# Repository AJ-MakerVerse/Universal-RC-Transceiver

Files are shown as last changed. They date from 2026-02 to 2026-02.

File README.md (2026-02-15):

**Universal RC Transceiver**

This project is a high-performance, DIY Radio Control Transmitter designed to be a "Master Remote" for future robotics projects. While the transmitter is a complete hardware build (Universal PCB + 3D Printed Case), the receiver is provided as a reference prototype to jumpstart integration into any Arduino-based vehicle.

**The Vision**  
The goal was to create a single, reliable handheld controller with a standardized data packet. Whether you are building a drone, a rover, or a robotic arm, you simply drop the provided Receiver code into your project and start mapping controls.

**Features**  
Hardware Capabilities:

* Multi-Input Control: Supports 2 Joysticks (4-axis), 2 Potentiometers, 4 DPDT Switches, and 2 Push Buttons.
* Motion Control: Integrated MPU-6500 IMU allows for tilt-based steering (Pitch/Roll) with a dedicated "Tare" deadman switch.
* Universal Build: Designed for a standard Universal PCB (Perfboard), making it accessible for DIY builders.
* Ergonomic Design: Custom 3D-printable housing for a professional handheld feel.

Firmware Intelligence:

* High-Speed Link: Operates at 100Hz (10ms refresh rate) for low-latency control.
* Optimized Payload: Uses a Packed C++ Struct (17 bytes) to fit all data into a single nRF24L01 packet (under the 32-byte limit).
* Bit-Packing: Compresses 8 digital inputs into a single byte to save bandwidth and improve reliability.
* Error Handling: Built-in LED blink codes for hardware troubleshooting (Radio or IMU disconnected).
* Robust Protocol: Uses 16-bit CRC error detection, Auto-Acknowledgment, and a specific 250kbps data rate for maximum range and penetration.

**Project Structure**  
This repository is organized into two main modules:

**1. Transmitter (TX)**  
The control hub of the system.

* Firmware: Source code and library dependencies.
* Hardware: Universal PCB layout and wiring diagrams.
* STLs: 3D Printable files for the transmitter case.

**2. Receiver (RX)**  
The vehicle/device-side module.

* Firmware: Reference code to parse data and print to Serial Monitor.
* Hardware: Breadboard wiring guide for prototyping.

Each sub-folder contains its own dedicated README with specific assembly and setup instructions.

**Quick Start**  

* Build the Hardware: Start with the Transmitter Hardware Guide.
* Library: Install RF24 and FastIMU libraries in your Arduino IDE.
* Flash the Code: Upload the TX Firmware and RX Firmware.
* Test: Power on both units and verify the link.

**License**  
This project is licensed under the MIT License.

**Contributing**  
Feel free to fork this project, report bugs via Issues, or submit Pull Requests to improve the protocol or hardware designs!

**To see more of my projects, feel free to connect with me on LinkedIn - https://www.linkedin.com/in/abhayjain-makerverse**

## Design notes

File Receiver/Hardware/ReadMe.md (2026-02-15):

**Receiver Hardware**

This folder contains the wiring instructions for the receiver prototype. Currently, the receiver is designed for a breadboard setup to allow for quick testing and easy integration into different projects.

**Documentation Files**	

* Breadboard Diagram: Visual guide for jumper wire placement.
* Bill of Materials (BoM): A full list of components required for the build.

**Pin Mapping (Arduino Nano)**  
Since the receiver only requires the nRF24L01 module, the wiring is straightforward:

* VCC  = 3.3V
* GND  = GND	
* CE   = D9	 
* CSN  = D10	 
* SCK  = D13	
* MOSI = D11	
* MISO = D12

**Pro Tip:** Breadboards are notorious for "noisy" power lines. If the receiver is struggling to stay connected, plug a 10µF-100µF capacitor directly into the breadboard across the nRF24L01's VCC and GND pins.

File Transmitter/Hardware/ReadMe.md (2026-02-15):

**Transmitter Hardware**  

This folder contains the physical assembly details for the Universal RC Transmitter. The build is designed to be soldered onto a standard Universal PCB for a compact and durable finish.

**Documentation Files**
* Wiring Diagram: The complete schematic and point-to-point wiring guide.  
* Bill of Materials (BoM): A full list of components required for the build.

**Pin Mapping Table**  
Use the follwoing list to wire your components to the Arduino Nano:  

**Digital Inputs (Switches & Buttons)**

* DPDT_1 =  D6	
* DPDT_2 =	D7	
* DPDT_3 =	D0 (RX)	
* DPDT_4 =	D1 (TX)	
* PB_1   =	D5	
* PB_2   =	D2	
* Tare   =  D8

**Analog Inputs (Joysticks \& Pots)**

* JS_1_VRy = A0	
* JS_1_VRx = A1	
* JS_1_SW  = D4	
* JS_2_VRy =	A6	
* JS_2_VRx =	A7	
* JS_2_SW  =	D3	
* Pot_1    =	A2	
* Pot_2		 =  A3

**Communication Modules**  
* nRF24L01 Radio 	\[I2C] -	D9 (CE), D10 (CSN), D11 (MOSI), D12(MISO), D13(SCK)
* MPU-6500 IMU	\[SPI] -	A4 (SDA), A5 (SCL)

**Assembly Notes**

Universal PCB Layout:

* Placement: Place the Arduino Nano in the center using female header pins. This allows you to replace the Nano if it ever burns out.
* Power: The nRF24L01 is very sensitive to power noise. It is highly recommended to solder a 10µF to 100µF capacitor across the VCC and GND pins of the radio module.
* Pull-ups: The firmware uses internal INPUT\_PULLUP. Ensure all switches and buttons are wired to GND when closed.

IMU Orientation:  
Mount the MPU-6500 flat on the PCB. If your "Forward" tilt is giving you "Roll" data instead of "Pitch," check the orientation of the module or adjust the axes in the firmware.

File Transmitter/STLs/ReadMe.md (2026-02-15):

**Transmitter STLs**

This folder contains the 3D-printable files for the transmitter enclosure. The design focuses on ergonomics, ensuring a comfortable grip for long sessions, and easy access to all switches and joysticks.

**STL Files**

* Enclosure - Top: The main faceplate with cutouts for joysticks, buttons, and switches.
* Enclosure - Bottom: The rear shell, designed to house the Universal PCB.
* Potentiometer - Knob: Custom-fit knobs for the two potentiometers (print 2x).
* Button - Cap: Protective caps for the tactile push buttons to improve surface area and feel (pint 3x). 

**Recommended Print Settings**  
For the best fit and durability, use the following settings:

* Material	-	PLA (for ease) or PETG (for durability)
* Layer Height	-	0.2mm
* Infill	-	10% (Lightning)
* Supports	-	None

**Post-Processing**  
If you notice stringing, abrasions, or if the parts aren't meshing perfectly, do some light sanding on the contact edges.

**Assembly**

* PCB Placement: 	Place the assembled Universal PCB/Transmitter unit into the Enclosure - Bottom. Ensure it is seated properly.
* Button Preparation: 	Place the 3 Button Caps into their respective slots in the Enclosure - Top.
* The Snap: 		Align the Enclosure - Top with the Enclosure - Bottom. Press firmly until you hear the parts snap together.
* Potentiometers: 	Screw on the metal nut that came with your potentiometer to secure the electronics to the shell.
* Knobs: 		Press the Potentiometer - Knob over the potentiometer shafts.
* Arduino: 		Finally, insert your Arduino Nano into the female header pins on your board.

**Troubleshooting**

* Tight Fit: If the cap stick, sand the sides down slightly, and ensure they move freely
* Alignment: Ensure that the components are aligned with enclosure's slots.

**You can also find the files on Printables:** https://www.printables.com/model/1602552-universal-rc-transceiver

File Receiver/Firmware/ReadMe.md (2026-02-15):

**Receiver Firmware**

This folder contains the reference code for the Arduino Nano receiver. Its primary purpose is to intercept the data packets from the Universal Transmitter and output the values to the Serial Monitor for debugging and calibration.

**Required Libraries**  
To compile this code, you must install the following library:

* RF24 (by TMRh20): For nRF24L01 radio communication.

**Logic Overview**  
The receiver acts as a passive listener. It is configured to match the Transmitter's settings exactly:

* Address: "00009"
* Channel: 105
* Data Rate: 250 kbps
* CRC: 16-bit

**The "Packed" Struct**  
The most critical part of this firmware is the Values struct. Because the Transmitter uses \_\_attribute\_\_((packed)), the Receiver must use the exact same definition to ensure the bytes align correctly in the Arduino's memory.

**Using the Serial Monitor**  
Once the code is flashed, open the Serial Monitor in the Arduino IDE to see the live data stream.

Settings:

* Baud Rate: 115200
* Format: The output will display PB (Push Buttons), DPDT (Switches), POT (Potentiometers), JS (Joysticks), and IMU (Pitch/Roll) values.

Reading the Output

* Digital Pins: Values are shown as 0 (Released) or 1 (Pressed).
* Analog Pins: Values range from 0 to 1023.
* IMU: Pitch and Roll are displayed in degrees. Note that the code divides the incoming value by 10 (e.g., a transmitted 450 becomes 45.0°).

**Troubleshooting the Link**  
If you don't see data in the Serial Monitor:

* Radio Check: On startup, the code checks if the nRF24L01 is connected. If you see "Radio Hardware Not Found!", check your SPI wiring.
* Address Mismatch: Ensure the Address variable in both TX and RX code is exactly "00009".
* Power Issues: The nRF24L01 on a breadboard is prone to electrical noise. If the data is "choppy" or stops randomly, add a capacitor (10µF+) across the radio's VCC and GND.

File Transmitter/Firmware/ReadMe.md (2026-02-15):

**Transmitter Firmware**

This folder contains the source code for the Universal RC Transmitter. The firmware is optimized for high-speed transmission (100Hz) and features advanced IMU data processing for motion control.

**Required Libraries**  
To compile this code, you must install the following libraries in the Arduino IDE:

* RF24 (by TMRh20): For nRF24L01 radio communication.
* FastIMU (by Tutto): For high-speed MPU-6500 data processing.
* SPI \& Wire: (Built-in Arduino libraries).

**Radio Configuration**  
The transmitter is configured for maximum reliability and low latency:

* Channel: 105 (2.505 GHz)
* Data Rate: 250 kbps (Chosen for better range and signal penetration).
* Payload: Dynamic payloads enabled with 16-bit CRC error detection.
* Power Level: Currently set to RF24\_PA\_MIN for bench testing.

Note: For field use, uncomment radio.setPALevel(RF24\_PA\_MAX); in the setup() function.

**Motion Control (IMU)**  
The firmware uses an MPU-6500 to calculate Pitch and Roll.

* Tare System: Pin D8 acts as a "Deadman Switch."
* The IMU only streams data when D8 is held down.
* On press, it "Tares" (zeros) the current orientation, allowing you to use the remote in any comfortable position.
* Complementary Filter: We use a filter coefficient of 0.96 to combine Accelerometer and Gyroscope data, providing smooth angles without "drift."

**Data Efficiency (Bit-Packing)**  
To keep the latency low, we pack all inputs into a custom C++ struct. This allows us to send 14 different inputs in a single 17-byte packet.

**Troubleshooting (Blink Codes)**  
If the transmitter fails to start, the Built-in LED (Pin 13) will blink a specific pattern:

* Single Blink: nRF24L01 Radio Hardware not found. Check SPI wiring and power.
* Double Blink: MPU-6500 IMU not found. Check I2C (A4/A5) connections.

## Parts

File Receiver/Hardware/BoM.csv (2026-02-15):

Item | Qty
Arduino UNO | x1
nRF24L01 | x1

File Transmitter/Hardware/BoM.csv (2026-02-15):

Item | Qty | Specs
Arduino Nano R3 | x1 | -
nRF24L01 | x1 | -
MPU - 6500 | x1 | -
Momentary Push Button | x3 | 12 x 12 x 7 mm
Potentiometer | x2 | B10K
HW - 504 Joystick | x2 | -
DPDT Slide Switch | x2 | 6 Pin
DC Barrel Power Jack | x1 | -
SPDT Slide Switch | x1 | -
Battery | x1 | 7V - 12V
Male & Female Header Pins | as req. | -
Jumper Wires | as req. | -
Universal PCB | x1 | S895

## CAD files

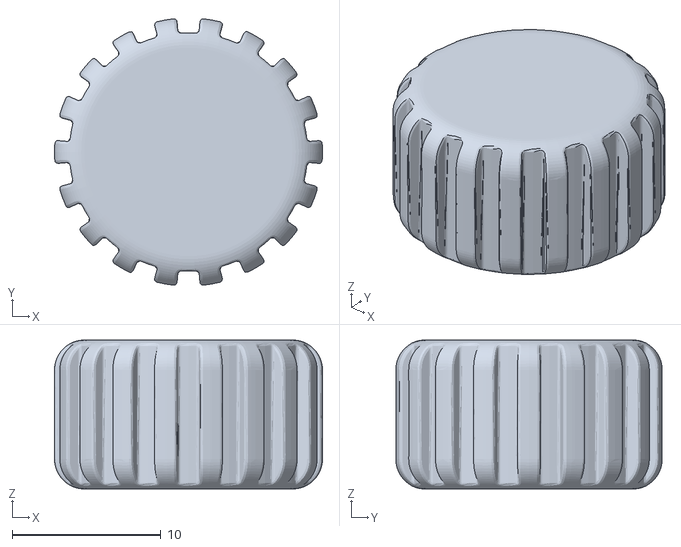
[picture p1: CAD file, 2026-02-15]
Transmitter/STLs/Potentiometer - Knob.stl
18.0 x 17.9 x 10.0

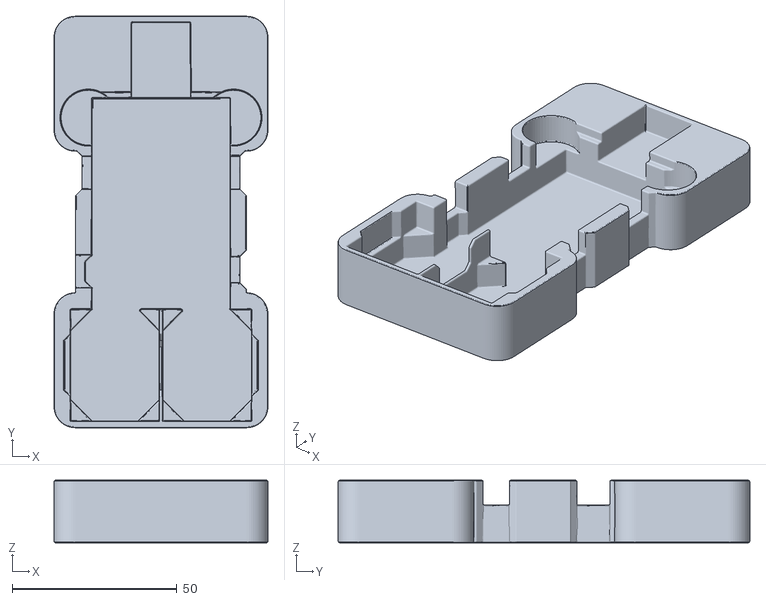
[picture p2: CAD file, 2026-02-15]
Transmitter/STLs/Enclosure - Bottom.stl
65.0 x 125.0 x 19.0

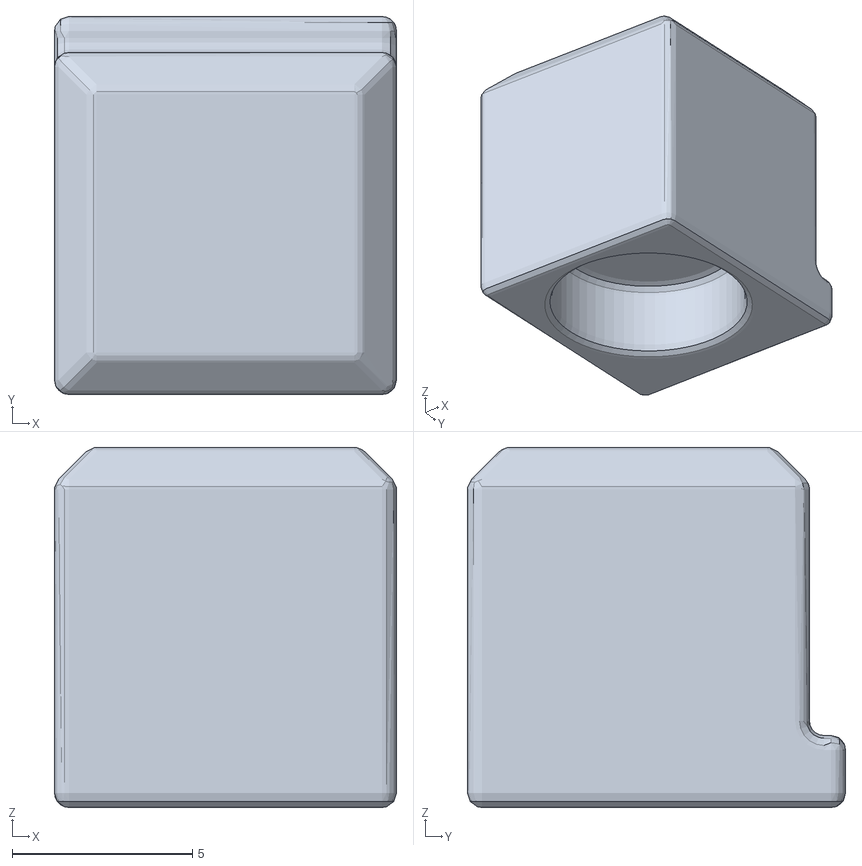
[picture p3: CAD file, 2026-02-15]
Transmitter/STLs/Button - Cap.stl
9.50 x 10.5 x 10.0

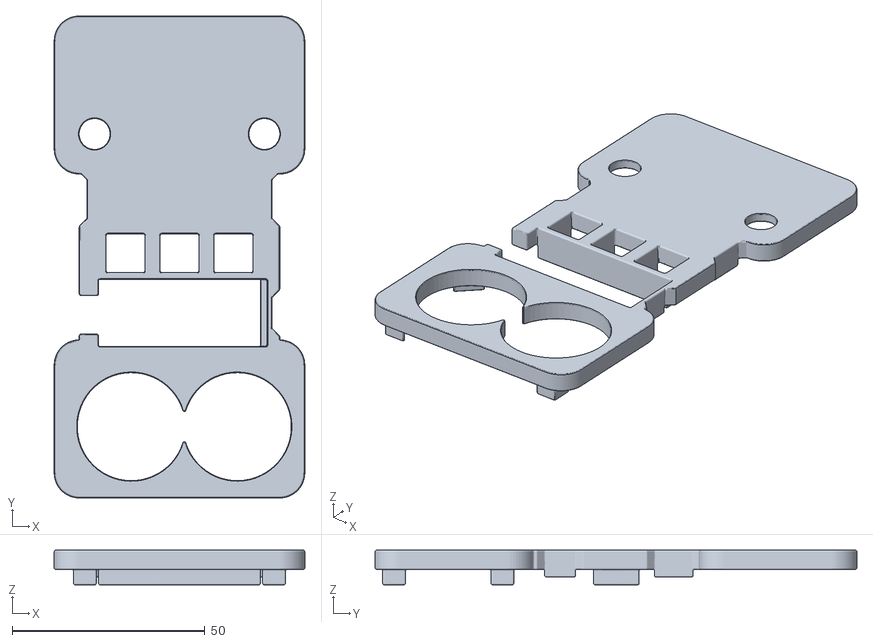
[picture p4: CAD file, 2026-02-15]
Transmitter/STLs/Enclosure - Top.stl
65.0 x 125.0 x 9.00

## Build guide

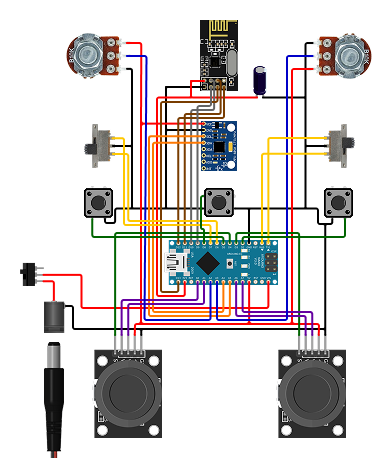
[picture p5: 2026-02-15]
Transmitter/Hardware/RC _ Transmitter Wiring Diagram.png

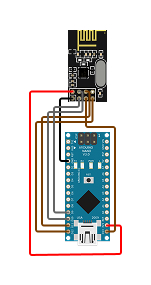
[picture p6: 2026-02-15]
Receiver/Hardware/RC_Receiver Wiring Diagram.jpg

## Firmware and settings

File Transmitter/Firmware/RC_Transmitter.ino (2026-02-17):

/*
Arduino Nano Pinout
  Digital Input:    |   Analog Input:    |    SPI Communication Pins:   |   I2C Communication Pins:

  RX0 = DPDT_4      |   A0 = JS_1_VRy    |    D9  = CE                  |   A4 = SDA
  TX1 = DPDT_3      |   A1 = JS_1_VRx    |    D10 = CSN                 |   A5 = SCL
  D2  = PB_2        |   A2 = POT_1       |    D11 = MOSI                |
  D3  = JS_2_SW     |   A3 = POT_2       |    D12 = MISO                |
  D4  = JS_1_SW     |   A6 = JS_2_VRy    |    D13 = SCK                 |
  D5  = PB_1        |   A7 = JS_2_VRx    |                              |
  D6  = DPDT_1      |                    |                              |
  D7  = DPDT_2      |                    |                              |
  D8  = Tare/PB_3   |                    |                              |
*/

//SPI Communication Library
#include <SPI.h>                                      //D11 = MOSI ; D12 = MISO ; D13 = SCK

//nRF24L01 Library
#include <nRF24L01.h>
#include <RF24.h>

//I2C Communication Library
#include <Wire.h>                                     //A4 = SDA ; A5 = SCL

//MPU-6500 Library
#include <FastIMU.h>

//CE, CSN Pins
RF24 radio(9, 10); 

//Transmitter Address
const byte Address[6] = "00009";                      //Must be same as Receiver Address

//MPU-6500 I2C Address
const uint8_t IMU_ADDRESS = 0x68;                     //IMU: Inertial Measurement Unit Sensor
const uint8_t Tare = 8;                               //IMU Deadman Switch

//MPU-6500 Object
MPU6500 IMU;

//IMU Data Structure
calData Calib;                                        //Calibration Data
AccelData Accel;                                      //Accelerometer Data
GyroData Gyro;                                        //Gyroscope Data

//Pitch and Roll Calculation Variables
float OAx, OAy, OAz, OGx, OGy;                        //Accel & Gyro Offset values 
float roll, pitch, sRoll, sPitch;                     //s : snapshot values
float alpha = 0.96;                                   //Complementary Filter
unsigned long time;
bool running = false;                                 //IMU Tracking Status

//Transmitter Data Type
struct __attribute__((packed)) Values{
  uint8_t Digital;                                    //8 digital inputs packed into 8 bits (Bit-Packing)     :1 Bytes
  uint16_t Analog[6];                                 //6 analog inputs (0 - 1023)                            :12 Bytes
  int16_t Euler[2];                                   //Euler Angles (Pitch and roll)                         :4 Bytes
};                                                    //Total                                                 :17 Bytes < 32 Bytes

//Transmitter Object
Values Data;

//Analog Input Pin Array
uint8_t analogPins[] = {A0, A1, A2, A3, A6, A7};

//Accel & Gyro Value Calibration Function
void calibrate(bool GyroOnly){
  float Ax=0, Ay=0, Az=0, Gx=0, Gy=0;
  for(int i=0; i<100; i++){
    IMU.update();                                     //Update IMU readings
    IMU.getAccel(&Accel); IMU.getGyro(&Gyro);         //Getting current IMU Data
    //Sum of 100 Values
    Ax+=Accel.accelX; Ay+=Accel.accelY; Az+=Accel.accelZ;     
    Gx+=Gyro.gyroX; Gy+=Gyro.gyroY;
    delay(5);
  }
  if(!GyroOnly){ 
    OAx=Ax/100; OAy=Ay/100; OAz=(Az/100)-1.0;         //Calculating Accel Offset Values as avg of 100 values
  }
  OGx=Gx/100; OGy=Gy/100;                             //Calculating Gyro Offset Values as avg of 100 values
}

//Euler Angles Calculation Function
void Angles(bool Track){
  IMU.update();                                       //Update IMU readings
  IMU.getAccel(&Accel); IMU.getGyro(&Gyro);           //Getting current IMU Data

  //Subtract the offset values from current values to get the data close to 0
  float Ax = Accel.accelX-OAx, Ay = Accel.accelY-OAy, Az = Accel.accelZ-OAz;    
  float Gx = Gyro.gyroX-OGx, Gy = Gyro.gyroY-OGy;

  float dt = (millis()-time)/1000.0; time = millis(); //Calculating Instantaneous time
  
  //Calculating Roll and Pitch based on Accel Values
  float rollAccel = atan2(Ay, Az) * 180.0/PI;
  float pitchAccel = atan2(-Ax, sqrt(Ay*Ay + Az*Az)) * 180.0/PI;

  if (Track){                                         //Jump directly to physical angle on first frame
    roll = rollAccel;
    pitch = pitchAccel;
  }
  else{                                               //Use normal filter during streaming
    roll = alpha * (roll + Gx * dt) + (1.0-alpha) * rollAccel;
    pitch = alpha * (pitch + Gy * dt) + (1.0-alpha) * pitchAccel;
  }
}

void setup(){
  //put your code here, to run once:

  Wire.begin();                                       //Initialize I2C Communication
  Wire.setClock(400000);                              //Set I2C to 400kHz for faster IMU updates

  //Initializing nRF24L01 Module
  if (!radio.begin()){                                //Initializes Radio Chip
    pinMode(13, OUTPUT);                              //Explicitly take control for error signal
    while (1){
      digitalWrite(13, HIGH); delay(1000);
      digitalWrite(13, LOW);  delay(2000);
      //Built-In LED - Single Blink : Radio is disconnected
    } 
  }                                                   //If radio fails, stop here (Safety Check)                                 

  radio.enableDynamicPayloads();                      //Allow Packets of different Byte sizes
  radio.setAutoAck(true);                             //Enables Auto-Acknowledgment
  radio.setCRCLength(RF24_CRC_16);                    //Uses a 16-bit checksum for better error detection

  radio.setChannel(105);                              //Channel 0-125 :: 2.4 - 2.525 GHz
  radio.setDataRate(RF24_250KBPS);                    //Sets Transmission Speed to 250 kbps (250 kbps - 2 Mbps)

  radio.setPALevel(RF24_PA_MIN);                      //Sets Power Amplifier (PA) to MINIMUM, Range: 1 - 2 Meters
  //radio.setPALevel(RF24_PA_LOW);                      //Range: 5 - 15 Meters
  //radio.setPALevel(RF24_PA_HIGH);                     //Range: 15 - 30 Meters
  //radio.setPALevel(RF24_PA_MAX);                      //Range: 30 - 70+ Meters

  radio.setRetries(5, 15);                            //1250us delay, 15 retries

  radio.openWritingPipe(Address);                     //Sets the destination address for transmission
  radio.stopListening();                              //Puts radio into Transmitter (TX) Mode

  //Initializing MPU-6500
  if(IMU.init(Calib, IMU_ADDRESS) !=0){               //Initializes IMU Chip
    pinMode(13, OUTPUT);                              //Explicitly take control for error signal
    while (1){
      digitalWrite(13, HIGH); delay(1000);
      digitalWrite(13, LOW);  delay(500);
      digitalWrite(13, HIGH); delay(1000);
      digitalWrite(13, LOW); delay(2000);
      //Built-In LED - Double Blink : IMU is disconnected
    }
  }                                                   //If IMU fails, stop here (Safety Check)

  //Setting Arduino digital pins as INPUT
  for(int i = 0; i <= 8; i++){
    pinMode(i, INPUT_PULLUP);
  }

  calibrate(0);                                       //Calibrating both Accel & Gyro

}

void loop(){
  //put your code here, to run repeatedly:

  static unsigned long lastSend = 0;
  if (millis() - lastSend < 10) return; 
  lastSend = millis();                                //Send data every 10ms (100Hz)

  //Store Roll and Pitch
  bool pressed = (digitalRead(Tare) == LOW);

  if (!running && pressed){                           //IMU is not tracking but the Button is pressed
    calibrate(1);                                     //Calibrating only Gyro to remove Gyro drift
    time = millis();                                  //Reset timer
    Angles(true);                                     //Force filter to match current tilt exactly
    sRoll = roll; sPitch = pitch;                     // Snapshot this as "Zero"
    running = true;                    
  } 
  else if (running){                                  //IMU is tracking
    if (!pressed){                                    //Button is released
      running = false; 
      Data.Euler[0] = 0;  Data.Euler[1] = 0;
    }else{
      Angles(false);                                  //Run normal filter
      Data.Euler[0] = (int16_t)((roll - sRoll) * 10);
      Data.Euler[1] = (int16_t)((pitch - sPitch) * 10);
    }
  }
  else{
    Data.Euler[0] = 0;  Data.Euler[1] = 0;
  }

  //Store Analog Input
  for (int i = 0; i < 6; i++){
    Data.Analog[i] = analogRead(analogPins[i]);
  }

  //Store Digital Input
  Data.Digital = 0;                                   //Clears the Bucket : 0000 0000
  //Data.Digital = ~(PIND);
  for (int i = 0; i <= 7; i++){
    if (digitalRead(i) == LOW){                       //Button pressed
      Data.Digital |= (1 << i);                       //Stores value at the 'i' bit
    }
  }

  radio.write(&Data, sizeof(Data));                   //Transmits the Data
  
}

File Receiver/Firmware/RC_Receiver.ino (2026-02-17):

//SPI Communication Library
#include <SPI.h>                                      //D11 = MOSI ; D12 = MISO ; D13 = SCK

//nRF24L01 Library
#include <nRF24L01.h>
#include <RF24.h>

//CE, CSN Pins
RF24 radio(9, 10); 

//Transmitter Address
const byte Address[6] = "00009";                      //Must be same as Transmitter Address

//Receiver Data Type: Must be same as Transmitter
struct __attribute__((packed)) Values{
  uint8_t Digital;
  uint16_t Analog[6];
  int16_t Euler[2];
}; 

//Receiver Object
Values Data;

void setup() {
  // put your setup code here, to run once:

  Serial.begin(115200);                               //Initialize Serial Monitor

  if (!radio.begin()) {
    Serial.println("Radio Hardware Not Found!");
    while (1);
  }                                                   //Safety Check

  radio.enableDynamicPayloads();                      //Allow Packets of different Byte sizes
  radio.setAutoAck(true);                             //Enables Auto-Acknowledgment
  radio.setCRCLength(RF24_CRC_16);                    //Uses a 16-bit checksum for better error detection

  radio.setChannel(105);                              //Channel 0-125 :: 2.4 - 2.525 GHz
  radio.setDataRate(RF24_250KBPS);                    //Sets Transmission Speed to 250 kbps (250 kbps - 2 Mbps)

  radio.setPALevel(RF24_PA_MIN);                      //Sets Power Amplifier (PA) to MINIMUM, Range: 1 - 2 Meters
  //radio.setPALevel(RF24_PA_LOW);                      //Range: 5 - 15 Meters
  //radio.setPALevel(RF24_PA_HIGH);                     //Range: 15 - 30 Meters
  //radio.setPALevel(RF24_PA_MAX);                      //Range: 30 - 70+ Meters

  radio.openReadingPipe(1, Address);                     //Sets the destination address for transmission
  radio.startListening();                             //Puts radio into Receiver (RX) Mode

  Serial.println("Receiver Initialized. Waiting for data...");
}

void loop() {
  // put your main code here, to run repeatedly:

  if (radio.available()){
    radio.read(&Data, sizeof(Data));                  //Reading the Struct

    // 1. Push Buttons (Pins D2 and D5)
    Serial.print("PB_1: ");       Serial.print((Data.Digital >> 5) & 0x01);
    Serial.print("  PB_2: ");     Serial.println((Data.Digital >> 2) & 0x01);

    // 2. DPDT Switches (Pins D0, D1, D6, D7)
    Serial.print("DPDT_1: ");     Serial.print((Data.Digital >> 6) & 0x01);
    Serial.print("  DPDT_2: ");   Serial.print((Data.Digital >> 7) & 0x01);
    Serial.print("  DPDT_3: ");   Serial.print((Data.Digital >> 1) & 0x01);
    Serial.print("  DPDT_4: ");   Serial.println((Data.Digital >> 0) & 0x01);

    //3. Potetiometers (Pins A2 and A3)
    Serial.print("POT_1: ");      Serial.print(Data.Analog[2]);
    Serial.print("  POT_2: ");    Serial.println(Data.Analog[3]);

    //4. Joysticks (Pins A0, A1, A6, A7, D3 and D4)
    Serial.print("JS_1_VRx: ");   Serial.print(Data.Analog[1]);
    Serial.print("  JS_1_VRy: "); Serial.print(Data.Analog[0]);
    Serial.print("  JS_1_SW: ");  Serial.print((Data.Digital >> 4) & 0x01);

    Serial.print("  JS_2_VRx: "); Serial.print(Data.Analog[5]);
    Serial.print("  JS_2_VRy: "); Serial.print(Data.Analog[4]);
    Serial.print("  JS_2_SW: ");  Serial.println((Data.Digital >> 3) & 0x01);

    //5. IMU Data (Pitch and Roll)
    Serial.print("Pitch: ");      Serial.print(Data.Euler[0] / 10.0, 1);
    Serial.print("  Roll: ");     Serial.println(Data.Euler[1] / 10.0, 1);

    Serial.println();
    
  } 
}

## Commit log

2026-02-15 Rename Wiring Diagram.png to RC_ Transmitter Wiring Diagram.png
2026-02-15 Rename RC_ Transmitter Wiring Diagram.png to RC _ Transmitter Wiring Diagram.png
2026-02-15 Update and rename BOM.csv to BoM.csv
    [BoM.csv]
